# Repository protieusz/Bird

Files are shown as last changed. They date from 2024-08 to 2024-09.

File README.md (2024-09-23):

# Bird
Bird, a variant mod of the Crowboard.  39 keys with a 25mm trackball in the center powered by RP2040-Core A.

# Featured On KBDNews
https://kbd.news/Bird-2471.html

# Full Production Pics














# Descripton
Bird is a heavily modified version of Crowboard which has been blessed by Doesntfazer | Keyboarddweebs.net himself for the mod. [Crowboard](https://github.com/doesntfazer/CrowBoard) was originally designed by Doesntfazer.

# Sponsorship
Thank you PCBWay for sponsoring my "BIRD"!
For all your PCB and PCBA needs, PCBWay is your only answer. PCBWay take the time to check the BOM file and the component placement file to make sure that it is up to specs. If there are any issues, PCBWay will email back and inform the customer if there are any corrections that need to be made and also provide solutions for the customer. I highly recommend PCBWay. Great customer service and quality PCBs that you cannot rely on.  I highly recommend them!

# A List Of Mods Made To The Original files by Doesntfazer:

-A circular hole was created in the middle that can accomodate either a 25mm trackball powered by PMW3360 sensor.

-A Chinese "Bird" character was extruded or embross above the trackball in the center. I have also made a "Ironman" theme embross logo case but that case will not be public due to copyright issue. 
Only the "Bird" logo case will be released to the public.

-A Ironman ball holder cover was purchased from AE to cover the 25mm trackball when not in use to prevent the ball from falling off. No I haven't had the time to learn new skills as how to design the
trackball holder to have notches that latches to the ball. The Ironman cover is initially use for push start button for cars. You can also do a search on AE for it. I will not provide the link here.

-Base of the trackball holder with lens cut out is integrated into the top case with integrated 5mm switch plate. Top case sits flush with pcb.

-Additional 3 keys were added below the trackball for use as right click, scroll lock and left click.

-Full keyboard case was created to house the PCB.

-First time I have the hot swappable Kailh PCB being sponsored. As of Aug 30, 2024, the sponsored PCB is still being assembly. As always print the PCB at your own risk.

-Bird is powered by RP2040 Core - A which you can get from AE. I will not provide the link since I don't get anything from the sellers at AE if I endorse it here. Do a search in AE.

-QMK code is borrowed from aki27 bally and modified the matrix to fit my Bird (no pun intended). No suppport will be given since I just copy and paste.

-Use M2 brass hot inserts 3.2mm diameter and 4mm length for the M2 screws to secure the case. I forgot how long is my M2 screws are but they should be greater than 10mm so estimated around 14.6mm. Play around with and buy multiple M2 lenght screws.

# Some Caveats

I printed the Ironman case with parts of the logo imbedded into the USB C case structure and therefore I made the PCB USB C port area extend out a bit but didn't account for the wide of the opening so case doesn't fully close. I will upload the original Bird designed PCB with no mods on the USB C port PCB area. Sponsored PCB was on the Ironman version with changes made to the USB C port PCB. However this version will not be release. Please print the untested "Bird" version. It should work and fit the case. The PCB components and routing designs are the same. Update: Fixed Bird Bottom case uploaded. Please use this instead of the "Bird Case Step". As always please print at your own risk.






# Renders



Screenshot 2024-07-03 at 8 15 54 PM
Screenshot 2024-07-03 at 8 07 34 PM
Screenshot 2024-07-03 at 8 07 01 PM
Screenshot 2024-07-03 at 8 06 35 PM
Screenshot 2024-07-03 at 8 06 03 PM
Screenshot 2024-07-04 at 10 05 26 PM
Screenshot 2024-07-04 at 10 05 14 PM
Screenshot 2024-07-04 at 10 05 05 PM
Screenshot 2024-07-04 at 10 04 42 PM




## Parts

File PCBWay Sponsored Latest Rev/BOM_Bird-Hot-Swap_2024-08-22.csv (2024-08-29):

ID | Name | Designator | Footprint | Quantity | Manufacturer Part | Manufacturer | Supplier | Supplier Part | Price | link
1 | DIODE-SOD123 | D000,D001,D002,D003,D004,D006,D007,D008,D009,D010,D100,D101,D102,D103,D104,D106,D107,D108,D109,D110,D200,D201,D202,D203,D204,D206,D207,D208,D209,D210,D301,D302,D303,D304,D305,D306,D307,D308,D309 | DIODE-SOD123 | 39 | SM4007PL | MDD(辰达半导体) | LCSC | C64898 | 0.006
2 | RP2040-Core-A | U1 | RP2040-CORE-A | 1 |  |  |  |  | [DNP不要贴];
3 | PMW3360DM-T2QU | U11 | PMW3360DM-T2QU.PACK | 1 | PMW3360DM-T2QU |  |  |  | [DNP不要贴]; | http://www.pixart.com/upload/PMS0058-PMW3360DM-T2QU-NNDS-R1.30-06042016_20160902201411.pdf
4 | TYPE-C-31-M-12 | USBC1 | USB-C_SMD-TYPE-C-31-M-12 | 1 | TYPE-C-31-M-12 | 韩国韩荣 | LCSC | C165948 | 0.161 | https://so.szlcsc.com/global.html?c=&k=C165948
5 | 4.7uF | C17,C19,C20 | C0402 | 3 | CL05A475MP5NRNC | SAMSUNG(三星) | LCSC | C23733 | 0.005 | https://lcsc.com/eda_search?q=C23733&%26type=1&ref=editor
6 | 100nF | C18 | C0402 | 1 | CL05B104KB54PNC | SAMSUNG(三星) | LCSC | C307331 | 0.005 | https://lcsc.com/eda_search?q=C307331&%26type=1&ref=editor
7 | PRTR5V0U2X,215 | D11 | SOT-143_L2.9-W1.3-P1.92-LS2.3-BR | 1 | PRTR5V0U2X,215 | Nexperia(安世) | LCSC | C12333 | 0.092 | https://item.szlcsc.com/280548.html
8 | BSMD0805-020-15V | F1 | F0805 | 1 | BSMD0805-020-15V | BHFUSE(佰宏) | LCSC | C883103 | 0.045 | https://item.szlcsc.com/343298.html
9 | 5.1kΩ | R1,R2 | R0402 | 2 | 0402WGF5101TCE | UNI-ROYAL(厚声) | LCSC | C25905 | 0.001 | https://item.szlcsc.com/323315.html
10 | 10kΩ | R10,R12,R13 | R0402 | 3 | 0402WGF1002TCE | UNI-ROYAL(厚声) | LCSC | C25744 | 0.001 | https://lcsc.com/eda_search?q=C25744&%26type=1&ref=editor
11 | 39Ω | R11 | R0402 | 1 | 0402WGJ0390TCE | UNI-ROYAL(厚声) | LCSC | C25164 |  | https://lcsc.com/eda_search?q=C25164&%26type=1&ref=editor
12 | 15kΩ | R14 | R0402 | 1 | 0402WGF1502TCE | UNI-ROYAL(厚声) | LCSC | C25756 | 0.001 | https://lcsc.com/eda_search?q=C25756&%26type=1&ref=editor
13 | AP2127K-ADJTRG1 | U10 | SOT-23-5_L3.0-W1.7-P0.95-LS2.8-BR | 1 | AP2127K-ADJTRG1 | DIODES(美台) | LCSC | C96343 | 0.074 | https://lcsc.com/eda_search?q=C96343&%26type=1&ref=editor
14 | Kailh MX Hotswap | K000,K001,K002,K003,K006,K007,K008,K009,K010,K100,K101,K102,K103,K104,K106,K107,K108,K109,K110,K200,K201,K202,K203,K204,K206,K207,K208,K209,K210,K301,K302,K303,K304,K305,K306,K307,K308,K309,K004 | KAILH MX HOTSWAP | 39 | 4958 | Adafruit Industries LLC | Digi-Key | 1528-4958-ND | [DNP不要贴]; | https://www.digikey.fr/fr/products/detail/adafruit-industries-llc/4958/13997772

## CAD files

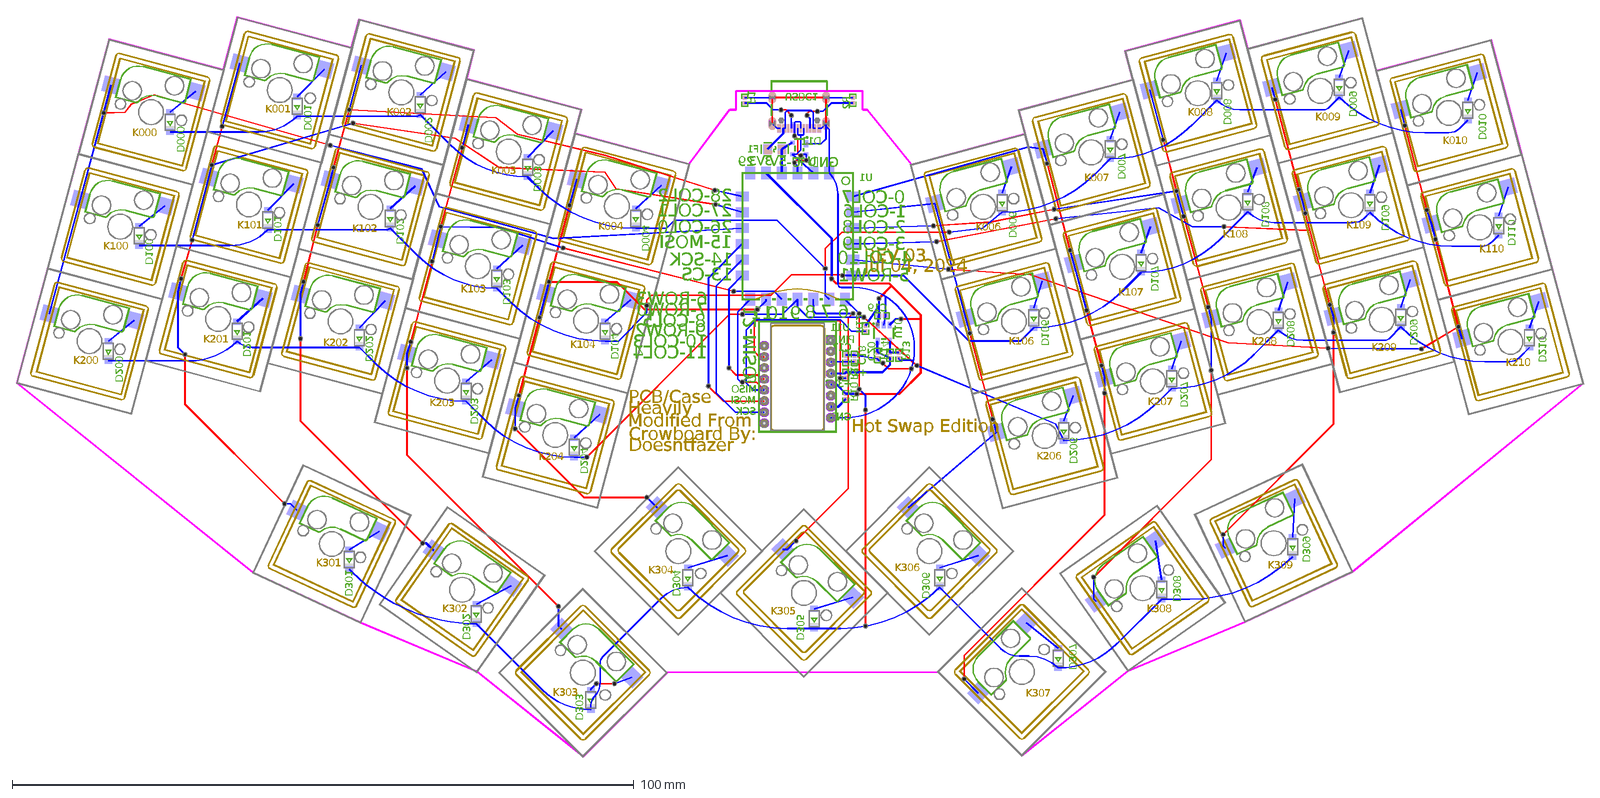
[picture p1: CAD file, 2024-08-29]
PCB_Bird-Hot-USB-Move-Upwards_2024-08-06.dxf
Heavily
Modified From
Crowboard By:
PCB/Case
REV 03
Jul 04, 2024
Hot Swap Edition
PIN 1
+2V
+3V3
GND
CS
MISO
MOSI
SCK
11-COL4
10-COL3
9-ROW2
8-COL5
7-ROW0
6-ROW3
Doesntfazer
D000
D001
D002
D003
D004
D006
D007
D008
D009
D010
D100
D101
D102
D103
D104
D106
D107
D108
D109
D110
D200
D201
D202
D203
D204
D206
D207
D208
D209
D210
D301
D302
D303
D304
D305
D306
D307
D308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

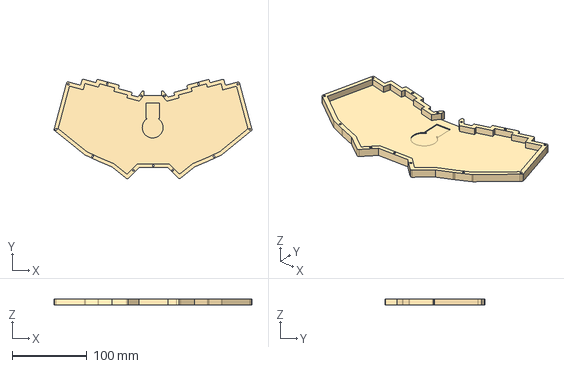
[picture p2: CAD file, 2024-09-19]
STEP/Bird fixed bottom.step
265.2 x 133.4 x 8.60 mm

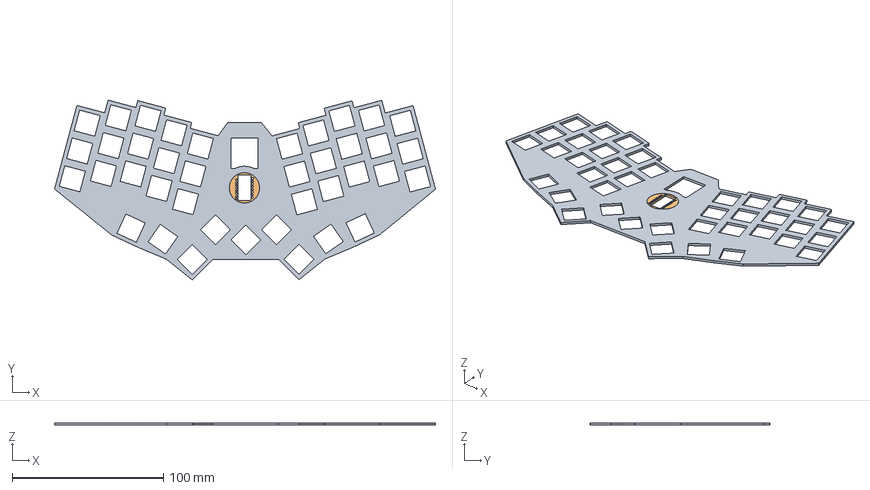
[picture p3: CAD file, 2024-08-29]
STEP/Bird PCB.step
251.9 x 118.9 x 1.60 mm

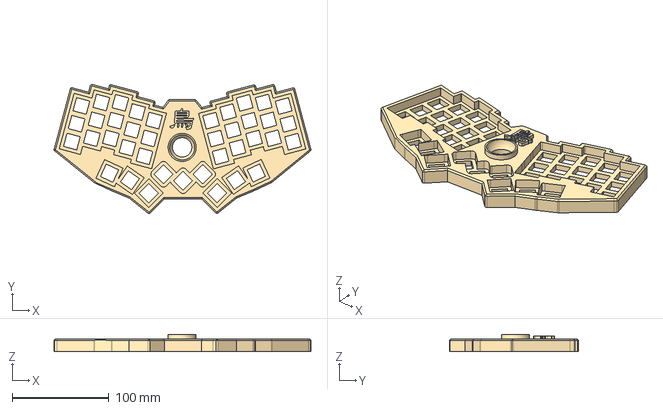
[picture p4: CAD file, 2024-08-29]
STEP/Bird Top.step
265.2 x 133.4 x 17.8 mm

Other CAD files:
STEP/Bird Bottom.step
Bird Bottom.stl
Bird Top.stl

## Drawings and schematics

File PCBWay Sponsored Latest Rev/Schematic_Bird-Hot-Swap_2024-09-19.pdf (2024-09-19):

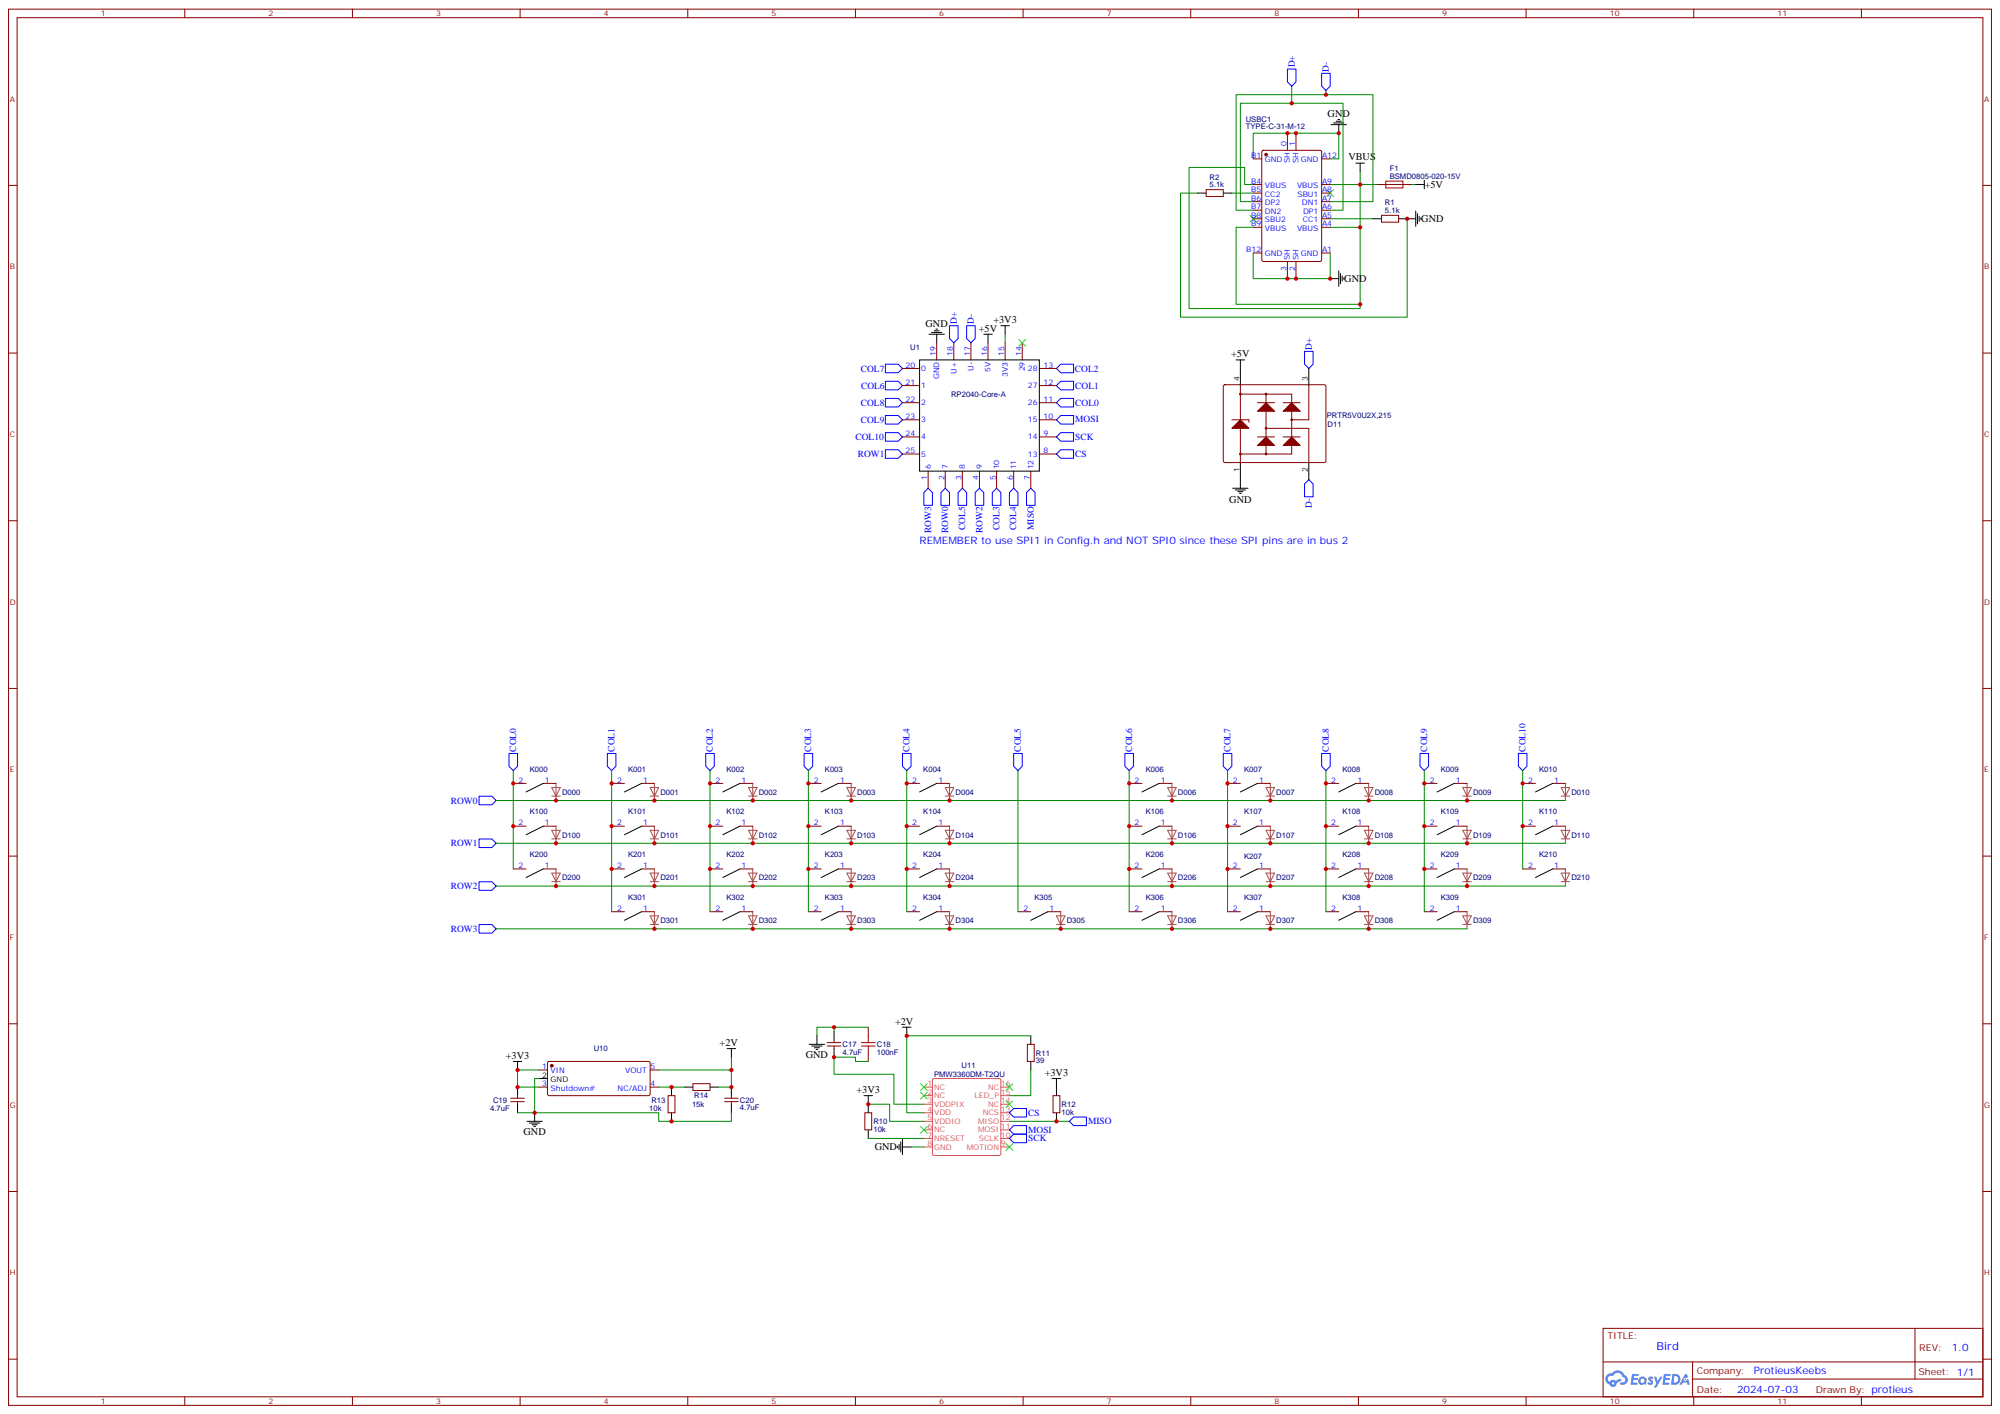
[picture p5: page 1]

REMEMBER to use SPI1 in Config.h and NOT SPI0 since these SPI pins are in bus 2 ROW³

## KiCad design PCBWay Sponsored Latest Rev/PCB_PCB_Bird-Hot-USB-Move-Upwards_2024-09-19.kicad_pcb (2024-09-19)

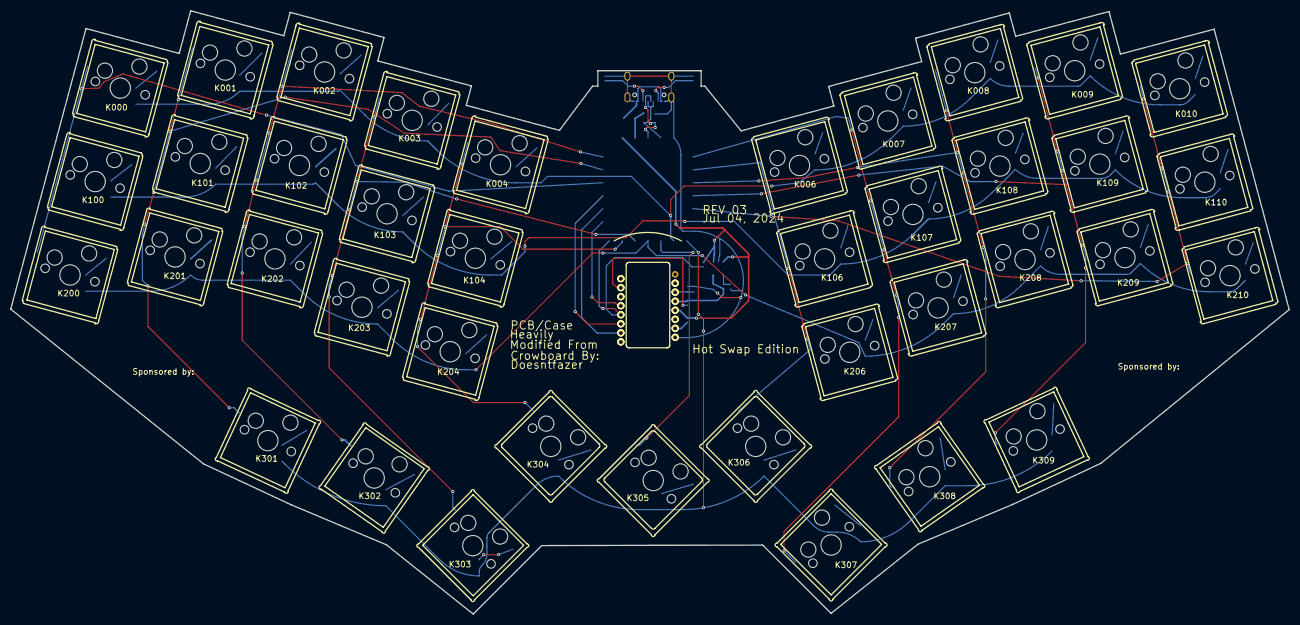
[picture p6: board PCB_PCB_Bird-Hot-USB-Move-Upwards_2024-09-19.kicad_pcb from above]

Board: 2 copper layers, 251.9 x 118.9 mm, 95 parts (0 on the bottom side), 71 nets.

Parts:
C17, C19, C20: 4.7uF; C0402
C18: 100nF; C0402
D000, D001, D002, D003, D004, D006, D007, D008, D009, D010, D100, D101, D102, D103, D104, D106, D107, D108, D109, D110, D200, D201, D202, D203, D204, D206, D207, D208, D209, D210, D301, D302, D303, D304, D305, D306, D307, D308, D309: DIODE-SOD123
D11: PRTR5V0U2X,215; SOT-143_L2.9-W1.3-P1.92-LS2.3-BR
F1: BSMD0805-020-15V; F0805
K000, K001, K002, K003, K004, K006, K007, K008, K009, K010, K100, K101, K102, K103, K104, K106, K107, K108, K109, K110, K200, K201, K202, K203, K204, K206, K207, K208, K209, K210, K301, K302, K303, K304, K305, K306, K307, K308, K309: Kailh MX Hotswap; KAILH MX HOTSWAP
R1, R2: 5.1kΩ; R0402
R10, R12, R13: 10kΩ; R0402
R11: 39Ω; R0402
R14: 15kΩ; R0402
U1: 5-ROW1; RP2040-CORE-A
U10: AP2127K-ADJTRG1; SOT-23-5_L3.0-W1.7-P0.95-LS2.8-BR
U11: PMW3360DM-T2QU; PMW3360DM-T2QU.PACK
USBC1: TYPE-C-31-M-12; USB-C_SMD-TYPE-C-31-M-12

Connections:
+2V: C20.2, R11.2, R14.2, U10.5, U11.4
+3V3: C19.2, R10.2, R12.2, U1.15, U10.1, U10.3, U11.5
+5V: D11.4, F1.2, U1.16
COL0: K000.2, K100.2, K200.2, U1.11
COL1: K001.2, K101.2, K201.2, K301.2, U1.12
COL2: K002.2, K102.2, K202.2, K302.2, U1.13
COL3: K003.2, K103.2, K203.2, K303.2, U1.5
COL4: K004.2, K104.2, K204.2, K304.2, U1.6
COL5: K305.2, U1.3
COL6: K006.2, K106.2, K206.2, K306.2, U1.21
COL7: K007.2, K107.2, K207.2, K307.2, U1.20
COL8: K008.2, K108.2, K208.2, K308.2, U1.22
COL9: K009.2, K109.2, K209.2, K309.2, U1.23
COL10: K010.2, K110.2, K210.2, U1.24
CS: U1.8, U11.13
D000_A: D000.A, K000.1
D001_A: D001.A, K001.1
D002_A: D002.A, K002.1
D003_A: D003.A, K003.1
D004_A: D004.A, K004.1
D006_A: D006.A, K006.1
D007_A: D007.A, K007.1
D008_A: D008.A, K008.1
D009_A: D009.A, K009.1
D010_A: D010.A, K010.1
D100_A: D100.A, K100.1
D101_A: D101.A, K101.1
D102_A: D102.A, K102.1
D103_A: D103.A, K103.1
D104_A: D104.A, K104.1
D106_A: D106.A, K106.1
D107_A: D107.A, K107.1
D108_A: D108.A, K108.1
D109_A: D109.A, K109.1
D110_A: D110.A, K110.1
D200_A: D200.A, K200.1
D201_A: D201.A, K201.1
D202_A: D202.A, K202.1
D203_A: D203.A, K203.1
D204_A: D204.A, K204.1
D206_A: D206.A, K206.1
D207_A: D207.A, K207.1
D208_A: D208.A, K208.1
D209_A: D209.A, K209.1
D210_A: D210.A, K210.1
D301_A: D301.A, K301.1
D302_A: D302.A, K302.1
D303_A: D303.A, K303.1
D304_A: D304.A, K304.1
D305_A: D305.A, K305.1
D306_A: D306.A, K306.1
D307_A: D307.A, K307.1
D308_A: D308.A, K308.1
D309_A: D309.A, K309.1
D+: D11.3, U1.18, USBC1.A6, USBC1.B6
D-: D11.2, U1.17, USBC1.A7, USBC1.B7
GND: C17.2, C18.2, C19.1, C20.1, D11.1, R1.2, R2.1, R13.1, U1.19, U10.2, U11.8, USBC1.0, USBC1.1, USBC1.2, USBC1.3, USBC1.A1, USBC1.A12, USBC1.B1, USBC1.B12
MISO: R12.1, U1.7, U11.12
MOSI: U1.10, U11.11
R1_1: R1.1, USBC1.A5
R2_2: R2.2, USBC1.B5
ROW0: D000.C, D001.C, D002.C, D003.C, D004.C, D006.C, D007.C, D008.C, D009.C, D010.C, U1.2
ROW1: D100.C, D101.C, D102.C, D103.C, D104.C, D106.C, D107.C, D108.C, D109.C, D110.C, U1.25
ROW2: D200.C, D201.C, D202.C, D203.C, D204.C, D206.C, D207.C, D208.C, D209.C, D210.C, U1.4
ROW3: D301.C, D302.C, D303.C, D304.C, D305.C, D306.C, D307.C, D308.C, D309.C, U1.1
SCK: U1.9, U11.10
U10_4: R13.2, R14.1, U10.4
U11_3: C17.1, C18.1, U11.3
U11_7: R10.1, U11.7
U11_15: R11.1, U11.15
VBUS: F1.1, USBC1.A4, USBC1.A9, USBC1.B4, USBC1.B9

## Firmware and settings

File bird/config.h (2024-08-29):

// Copyright 2024 ProtieusKeebs
// SPDX-License-Identifier: GPL-2.0-or-later

#pragma once

//#define VIAL_KEYBOARD_UID {0xC4, 0x18, 0xCC, 0x6D, 0x1C, 0x16, 0x5B, 0x8D}
//#define VIAL_UNLOCK_COMBO_ROWS {0, 0}
//#define VIAL_UNLOCK_COMBO_COLS {1, 11}

/* VIA */
//#define DYNAMIC_KEYMAP_LAYER_COUNT 8


/* key matrix size */
//#define MATRIX_COLS 13
//#define MATRIX_ROWS 4


/* tapping term */
// #define TAPPING_FORCE_HOLD
//#define TAPPING_TERM 200
// #define IGNORE_MOD_TAP_INTERRUPT

#define RP2040_BOOTLOADER_DOUBLE_TAP_RESET // Activates the double-tap behavior
#define RP2040_BOOTLOADER_DOUBLE_TAP_RESET_TIMEOUT 200U // Timeout window in ms in which the double tap can occur.

#ifdef COMBO_ENABLE
#    define COMBO_COUNT 2
#    define COMBO_TERM 150
#endif

/* Encoder */
//#define ENCODERS_PAD_A { GP11 }
//#define ENCODERS_PAD_B { GP12 }
//#define ENCODER_RESOLUTION 4

/* Matrix*/
//#define MATRIX_COL_PINS { GP25, GP24, GP23, GP22, GP21, GP26, GP27, GP20, GP19, GP18, GP17, GP16, GP13 }
//#define MATRIX_ROW_PINS { GP28, GP10, GP14, GP15 }

/* COL2ROW, ROW2COL */
//#define DIODE_DIRECTION COL2ROW


/* Set 0 if debouncing isn't needed */
//#define DEBOUNCE 5


/* Mechanical locking support. Use KC_LCAP, KC_LNUM or KC_LSCR instead in keymap (Very Important for Scroll Lock!!!) */
#undef LOCKING_SUPPORT_ENABLE
/* Locking resynchronize hack */
#undef LOCKING_RESYNC_ENABLE


/* Trackball */

#ifdef POINTING_DEVICE_ENABLE

//#    undef RP_SPI_USE_SPI0
//#    define RP_SPI_USE_SPI0 TRUE
//#    undef RP_SPI_USE_SPI1
//#    define RP_SPI_USE_SPI1 FALSE
#    define SPI_DRIVER SPID1

//#    define SPI_SCK_PIN GP22 //6
//#    define SPI_MISO_PIN GP24 //4
//#    define SPI_MOSI_PIN GP23 //7
#    define SPI_SCK_PIN GP14
#    define SPI_MISO_PIN GP12
#    define SPI_MOSI_PIN GP15

#endif


#ifndef PMW33XX_CS_PIN
#    define PMW33XX_CS_PIN GP13
#endif
#define POINTING_DEVICE_INVERT_X
#define POINTING_DEVICE_INVERT_Y
//#define ROTATIONAL_TRANSFORM_ANGLE 90
#define POINTING_DEVICE_ROTATION_180

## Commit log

2024-08-29 Bird case stls
    [Bird Bottom.stl, Bird Top.stl]
2024-08-29 PCB DXF
    [PCB_Bird-Hot-USB-Move-Upwards_2024-08-06.dxf]
2024-08-29 Production Files Rev3
    [BOM_Bird-Hot-Swap_2024-08-22.csv, PickAndPlace_PCB_Bird-Hot-USB-Move-Upwards_2024-08-22.csv]
2024-08-29 Bird Case STEP
    [Bird Bottom.step, Bird PCB.step, Bird Top.step]
2024-09-19 Schematic & converted pcb file
    [PCB_PCB_Bird-Hot-USB-Move-Upwards_2024-09-19.kicad_pcb]
2024-09-19 Use this fixed bottom case.
    [Bird fixed bottom.step]
